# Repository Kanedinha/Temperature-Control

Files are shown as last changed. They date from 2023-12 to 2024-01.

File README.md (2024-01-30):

# Temperature-Control
 Assingment for Mecatronic subject of IPB

The main idea is use a triac and a optocoupler to control the number of sinusoidal cycles over the Load, so we can control de RMS Voltage over the Load. that circuit can be called as a solid state relay, this circuit already have modules projected to work in high voltage and high current.

To complete de feedback loop, we can use a simple NTC sensor. So the following schema is projected that way


The following block diagram is used to model the system:
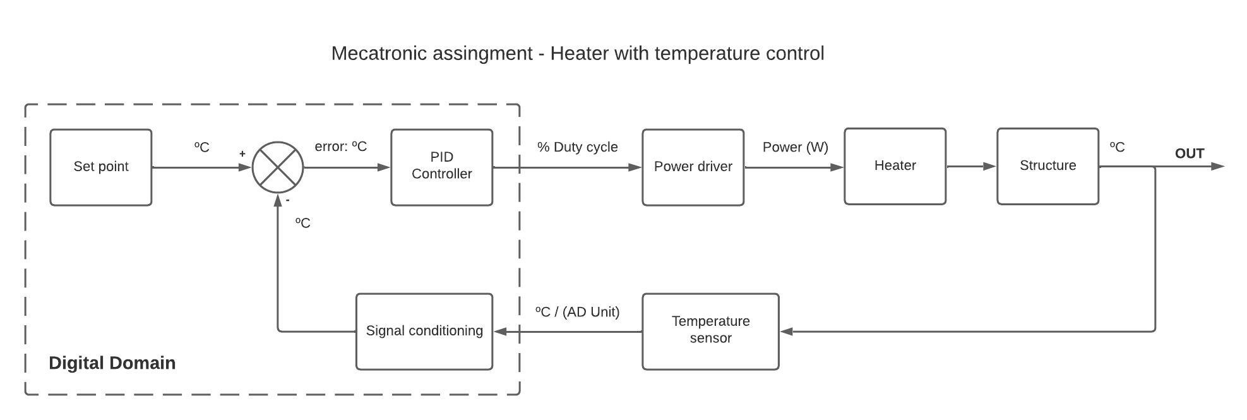
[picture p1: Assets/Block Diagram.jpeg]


One detail that impact the dinamic of system is de distance of the sensor from the heater, this mean the system have a slow response of the air temperature. this detail need to include in the system modeling.



For the PCB we can use the KiCAD project to guide us how to make an PCB, because how we will use a high voltage electrical network (230 Vrms; 50 Hz - in Portugal), its better use a PCB than a breadboard.


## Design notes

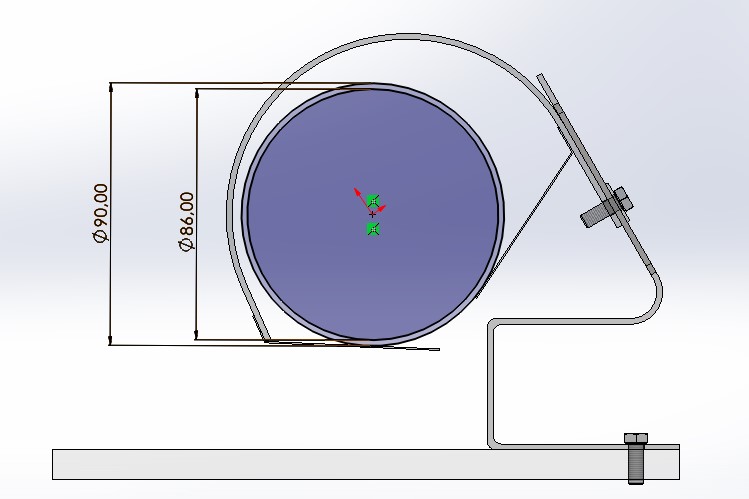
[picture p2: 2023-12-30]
Assets/Images/Diameter.jpg

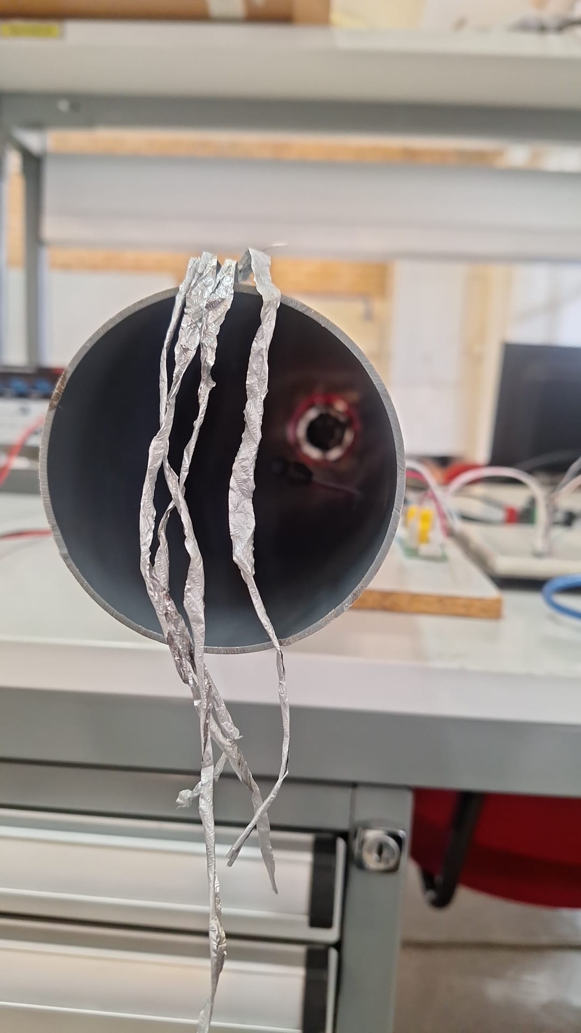
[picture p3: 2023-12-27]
Assets/Images/front_of_structure.jpeg

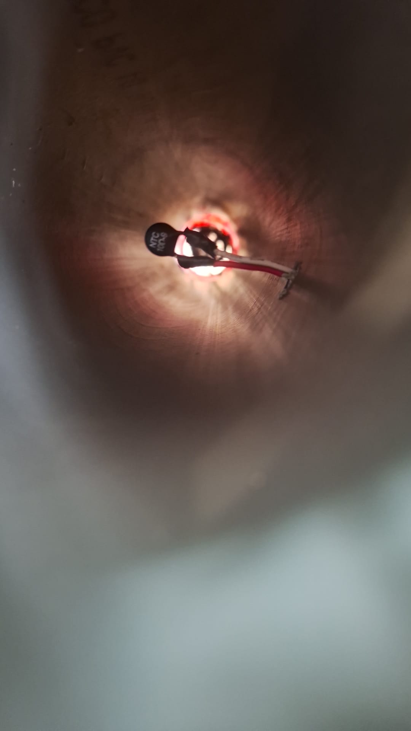
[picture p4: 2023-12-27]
Assets/Images/sensor.jpeg

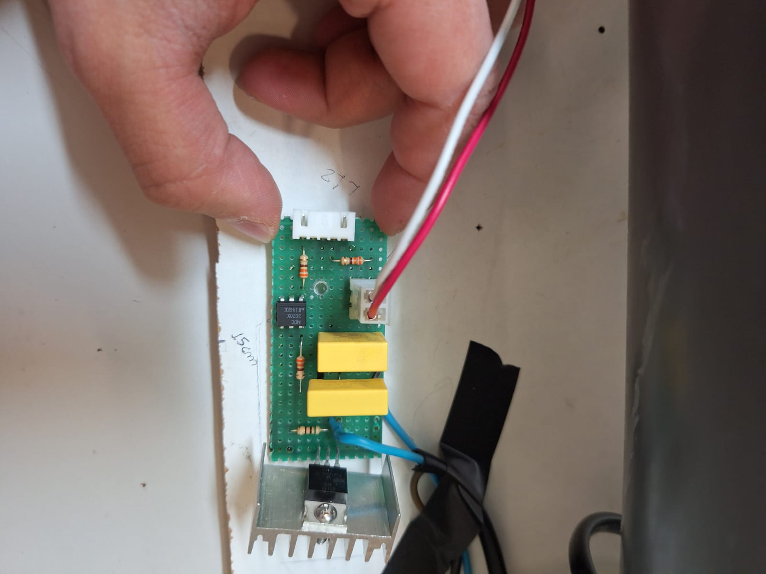
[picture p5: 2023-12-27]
Assets/Images/pcb.jpeg

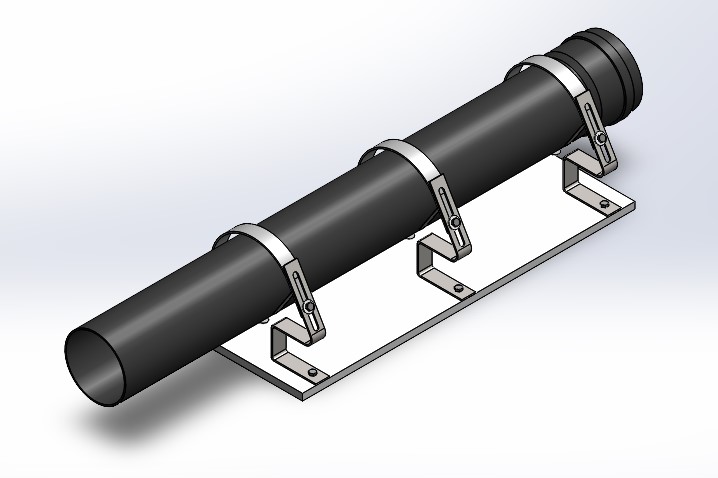
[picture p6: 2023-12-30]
Assets/Images/Structure.jpg

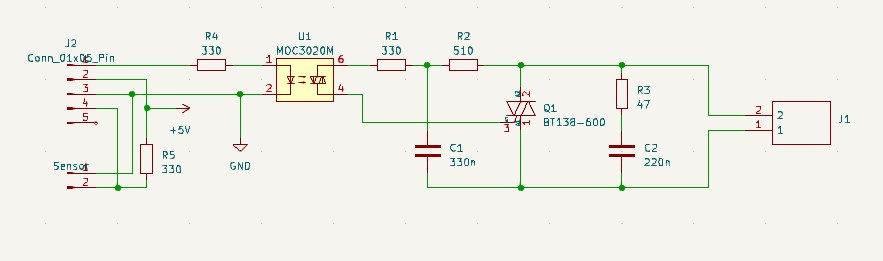
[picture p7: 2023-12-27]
Assets/Images/Schema.jpg

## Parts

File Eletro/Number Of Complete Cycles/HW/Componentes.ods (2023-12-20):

Part Number | quantidade | estoque | preço para compra | link
NTC 10D-9 termistor | 1 | 1
JC817 optocoupler transistor | 1 | 1
1n4007 diodos comuns | 4 | 6
BT138 Triac | 1 |  | 0,79 € | loja pm (https://www.lojapm.pt/product/triac-bt138-800v-12a-to220ab-igt-10-25ma-ifsm-95a-4q)
MOC3023 optocoupler diac | 1 |  | 0,33 € | loja pm (https://www.lojapm.pt/product/circuito-integrado-moc3023)
Resistor 33k 2W | 1 | 1
Capacitor de partida motor AC | 1 | 1
Resistor pulldown para NTC | 1 | 1
Resistor 330R | 1 | 1
Resistor 10k | 2 | 2
Capacitor 220nF | 1
Arduino / ESP32 | 1 | 4
LED verde (power on indicator) | 2 | 5
LED vermelho (Shutdown error indicator | 1 | 5

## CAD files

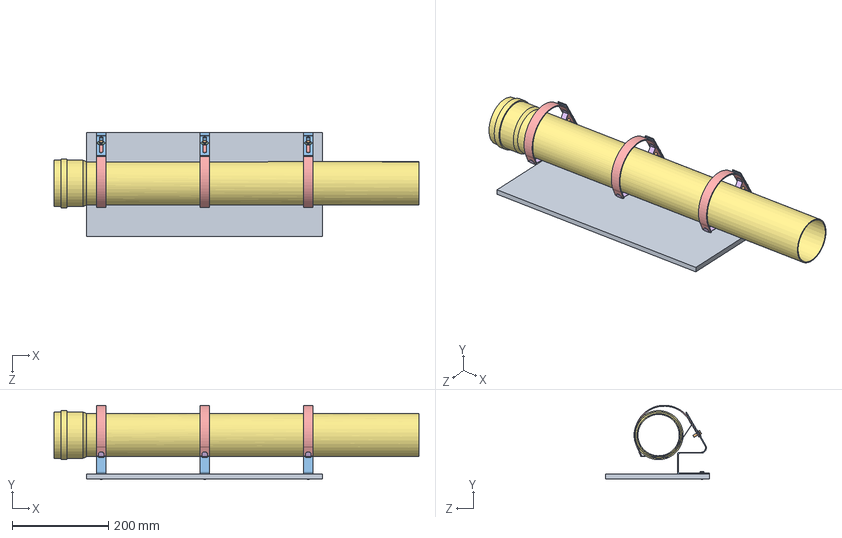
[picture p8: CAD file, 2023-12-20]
Mecanic/Protótipo.SLDASM
758.0 x 154.6 x 215.0 mm
Tábua
DIN 933 bolt x 6
Pé x 3
Arroela x 3
Mão x 3
Dedo x 6
Tubo

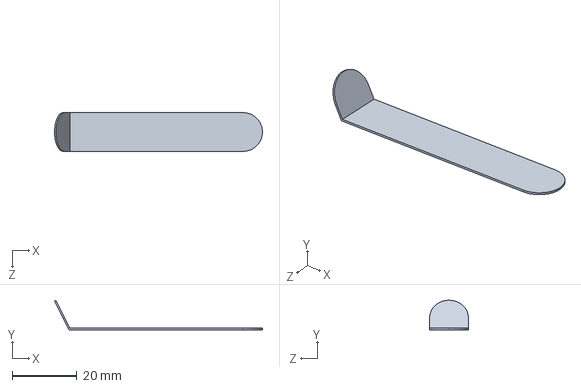
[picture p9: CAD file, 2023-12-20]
Mecanic/Dedo.SLDPRT
64.5 x 9.17 x 12.0 mm

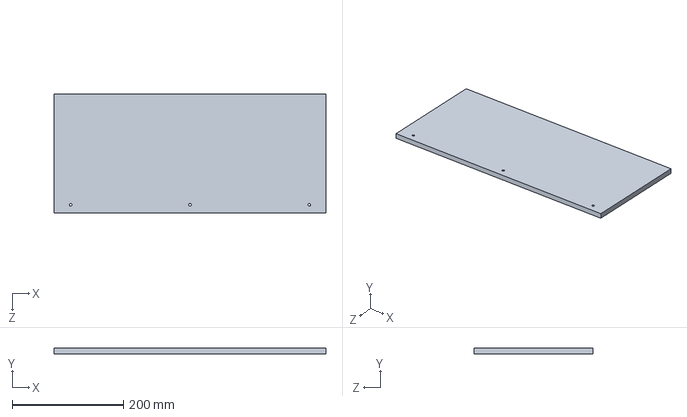
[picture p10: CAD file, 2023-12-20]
Mecanic/Tábua.SLDPRT
490.0 x 10.0 x 215.0 mm

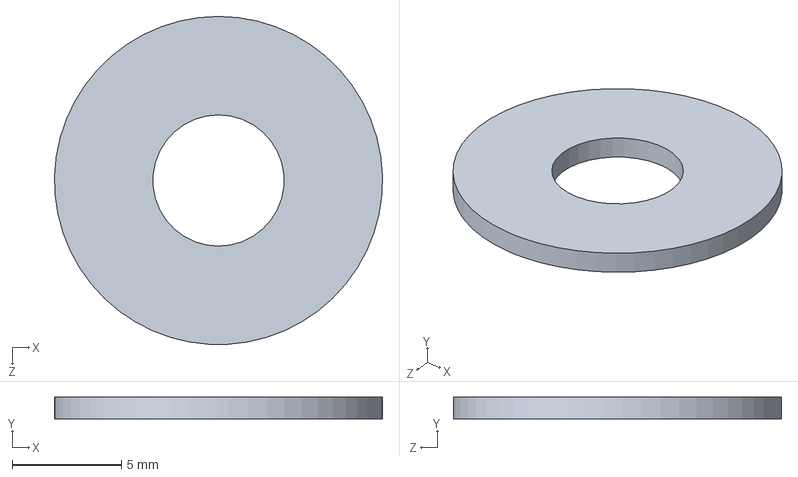
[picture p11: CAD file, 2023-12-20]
Mecanic/Arroela.SLDPRT
15.0 x 1.00 x 15.0 mm

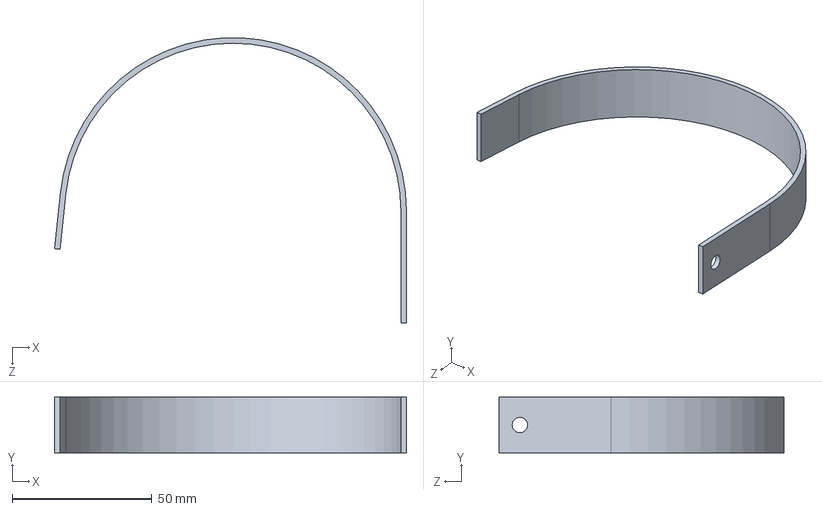
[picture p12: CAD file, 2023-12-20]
Mecanic/Mão.SLDPRT
125.8 x 20.0 x 101.9 mm

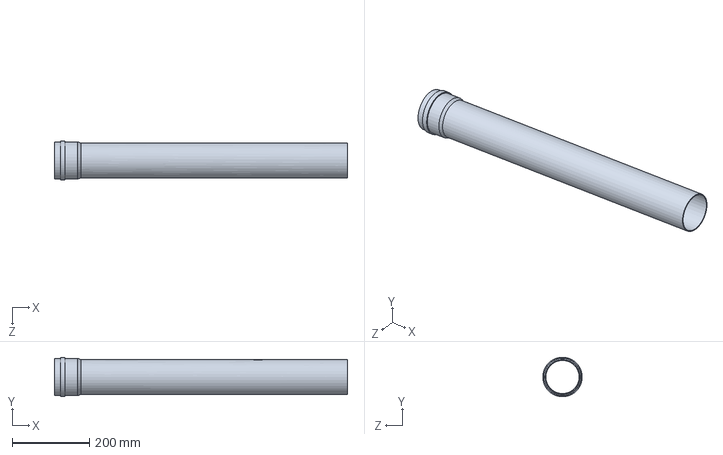
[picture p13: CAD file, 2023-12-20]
Mecanic/Tubo.SLDPRT
758.0 x 102.0 x 101.9 mm

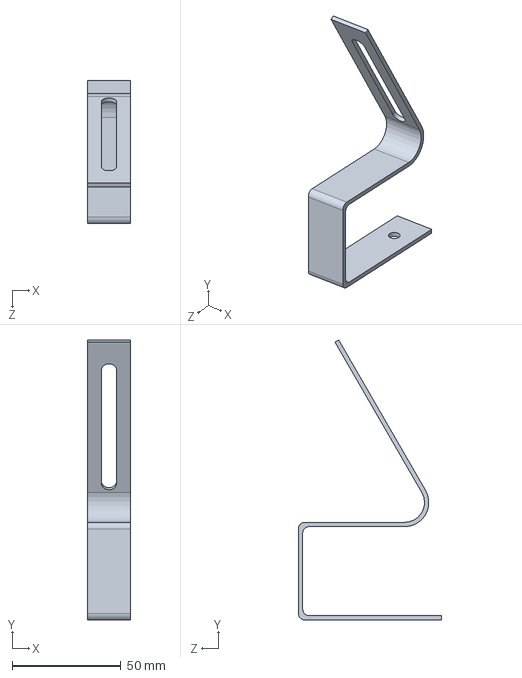
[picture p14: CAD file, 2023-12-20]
Mecanic/Pé.SLDPRT
20.0 x 128.9 x 66.0 mm

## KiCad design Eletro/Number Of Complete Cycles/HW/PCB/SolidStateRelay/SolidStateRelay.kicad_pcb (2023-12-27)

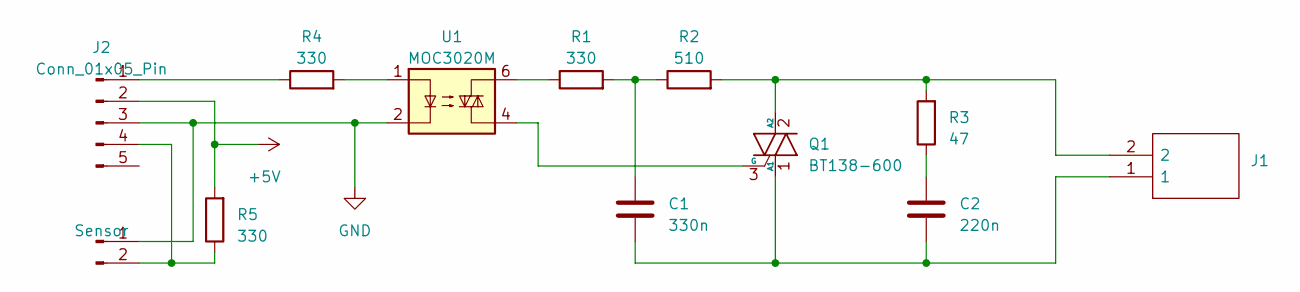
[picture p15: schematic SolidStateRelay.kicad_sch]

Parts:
C1: 330n; C_Rect_L9.0mm_W3.3mm_P7.50mm_MKT
C2: 220n; C_Rect_L9.0mm_W3.3mm_P7.50mm_MKT
J1: KRE_02; KRE02; Manufacturer_Part_Number KRE 02
J2: Conn_01x05_Pin; JST_EH_S5B-EH_1x05_P2.50mm_Horizontal
Q1: BT138-600; TO-220-3_Vertical
R1, R4, R5: 330; R_Axial_DIN0207_L6.3mm_D2.5mm_P10.16mm_Horizontal
R2: 510; R_Axial_DIN0207_L6.3mm_D2.5mm_P10.16mm_Horizontal
R3: 47; R_Axial_DIN0207_L6.3mm_D2.5mm_P10.16mm_Horizontal
Sensor: PinHeader_1x02_P2.54mm_Vertical
U1: MOC3020M; DIP-6_W7.62mm_LongPads

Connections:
+5V: J2.2, R5.2
GND: J2.3, Sensor.1, U1.2
unnamed: C1.1, R1.2, R2.1
unnamed: C2.1, R3.1
unnamed: J2.1, R4.1
unnamed: J2.4, R5.1, Sensor.2
unnamed: C1.2, C2.2, J1.1, Q1.1 (A1)
unnamed: J1.2, Q1.2 (A2), R2.2, R3.2
unnamed: Q1.3 (G), U1.4
unnamed: R1.1, U1.6
unnamed: R4.2, U1.1

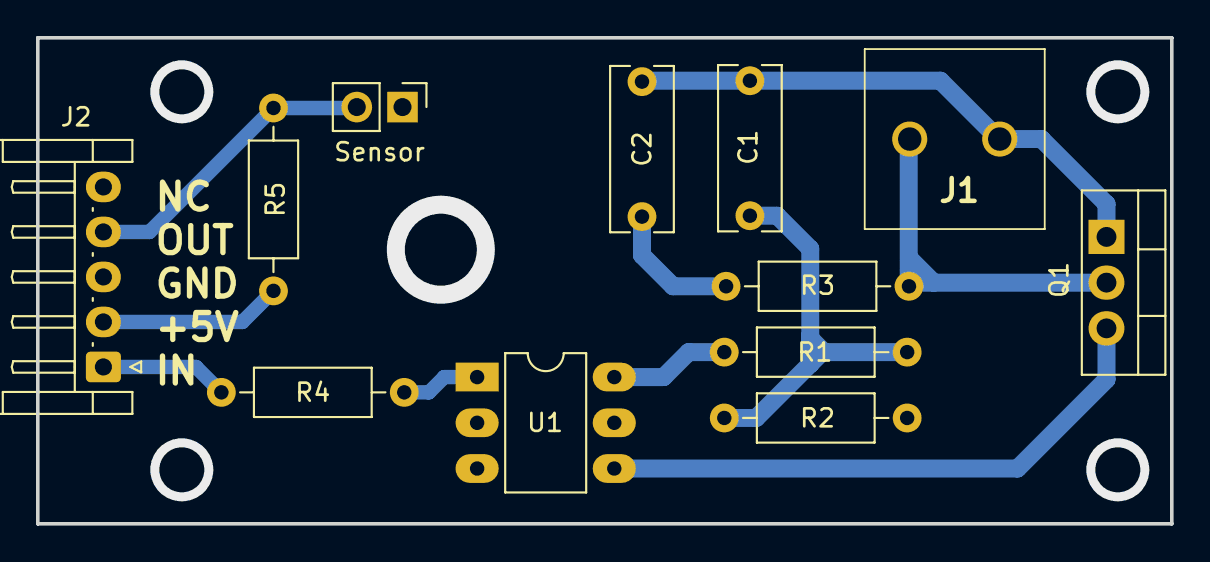
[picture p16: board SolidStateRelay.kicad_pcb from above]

Board: 2 copper layers, 63.0 x 27.0 mm, 12 parts (0 on the bottom side), 11 nets.

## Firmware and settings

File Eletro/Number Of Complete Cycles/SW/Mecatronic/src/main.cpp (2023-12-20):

#include <Arduino.h>
#include <Ticker.h>

// relation of the connector:
//
// GND (NTC)
// +5V (330R)
// GND (MOC3020)
// Sensor Out (NTC out)
// Optocoupler Input (MOC3020)
//
//
//

// ******* defines ******* //
#define TRIAC 13
#define NTC A0
#define Ntemp 20

// ******* flags ******* //
// bool ZC_flag = false;
// bool timer_flag = false;
bool onoff = false;

// ******* counters ******* //
uint8_t on_count = 0;
uint8_t off_count = 0;
uint8_t mean_count = 0;
uint8_t count = 0;

// ******* PID control vars ******* //
float set_point = 20.0; // em ºC
float erro = 0;
float integrator = 0;
float derivator = 0;
float Kp = 0.1;
float Ki = 0.01;
float Kd = 0;
float percent = 0.2;

// ******* signal vars ******* //
uint16_t AC_freq = 50;
float AC_period = 20; // millisseconds
uint8_t cycles = 100;
uint64_t time = 0, last_time = 0;

// ******* NTC sensor vars ******* //
uint16_t B = 3000;
float temp[Ntemp];
float mean = 0;
float analog_signal = 0;
float AD_value = 0;
float NTC_Res = 0;

// ******* Functions ******* //
void NCC_timer();
void PID_calc();

// ******* Timers ******* //
Ticker timer1(NCC_timer, AC_period, 0, MILLIS);
Ticker timer2(PID_calc, AC_period * 10, 0, MILLIS);

void NCC_timer()
{
  if (!onoff)
  {
    if (off_count >= (cycles - cycles * percent))
    {
      on_count = 0;
      onoff = !onoff;
      digitalWrite(TRIAC, HIGH);
      count++;
    }
    off_count++;
  }
  if (onoff)
  {
    if (on_count >= cycles * percent)
    {
      off_count = 0;
      onoff = !onoff;
      digitalWrite(TRIAC, LOW);
      count++;
    }
    on_count++;
  }
}

void PID_calc()
{
  erro = set_point - mean;
  integrator += erro;
  if (integrator > 10)
  {
    integrator = 10;
  }
  else if(integrator < -10){
    integrator = -10;
  }
  percent = Kp * erro + Ki * integrator;
  if(percent < 0)
    percent = 0;
}

void setup()
{
  pinMode(TRIAC, OUTPUT);
  pinMode(NTC, INPUT);
  Serial.begin(9600);

  timer1.start();
  timer2.start();

  digitalWrite(TRIAC, LOW);
}

void loop()
{
  if (Serial.available() > 0)
  {                                  
    // set_point = Serial.parseFloat(); 
    String dadosRecebidos = Serial.readStringUntil('\n');

    set_point = dadosRecebidos.substring(0, dadosRecebidos.indexOf(';')).toFloat();
    if(set_point > 30){
      set_point = 30;
    }

    dadosRecebidos.remove(0, dadosRecebidos.indexOf(';') + 1);

    Kp = dadosRecebidos.substring(0, dadosRecebidos.indexOf(',')).toFloat();
    dadosRecebidos.remove(0, dadosRecebidos.indexOf(';') + 1);

    Ki = dadosRecebidos.toFloat();
    
    integrator = 0;
  }

  if (mean_count > Ntemp)
  {
    Serial.print(mean / Ntemp);
    Serial.print(";");
    Serial.print(set_point);
    Serial.print(";");
    Serial.print(percent);
    Serial.print(";");
    Serial.print(integrator);
    Serial.print(";");
    Serial.println(onoff);
    mean_count = 0;
    mean = 0;
  }

  AD_value = analogRead(NTC);
  analog_signal = (AD_value / 1023) * 5;
  NTC_Res = analog_signal / (5 - analog_signal) * 330;
  temp[mean_count] = 1 / (log(NTC_Res / 10) / 3000 + 1 / (25 + 273.15)) - 273.15;
  mean += temp[mean_count];
  mean_count++;

  timer1.update();
  timer2.update();
}

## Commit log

2023-12-20 project is working
    [Arroela.SLDPRT, Componentes.ods, Dedo.SLDPRT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]
2023-12-27 PCB update
    [SolidStateRelay.kicad_pcb, SolidStateRelay.kicad_sch]
2023-12-27 kicad some zip file
2024-01-02 final schematic
